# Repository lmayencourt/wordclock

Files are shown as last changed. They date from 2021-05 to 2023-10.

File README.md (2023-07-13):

# Wordclock
*WordClock* is a hobby project, aiming to create a nice looking time keeping art work.

The secondary goal is to have a project to experiment with various technologies like Rust, laser cutting, 3d printing, and various engineering skills like software architecture, software requirements, Test-Driven Development and technical documentation.

## User guide
The [User guide](https://lmayencourt.github.io/wordclock/user_guide_hw_v2.html) is part of the GitHub page documentation.

## Project management
A [GitHub project](https://github.com/users/lmayencourt/projects/1/) is used for tasks management.
The project follow the [Semantic versioning](https://semver.org) scheme.

## Deploy the firmware to an ESP32 board
````
. ~/export-esp.sh
cargo xbuild
espflash /dev/tty.usbserial-0001 crates/cross_compiled/target/xtensa-esp32-espidf/debug/cross_compiled --flash-freq 80M --flash-size 4MB --flash-mode DIO --speed 921600 --partition-table crates/cross_compiled/esp32_ota_partitions.csv
````

Add `--monitor` option to `espflash` to open the serial consol of the device directly after flashing.

Follow the instruction from https://github.com/esp-rs/esp-idf-template to create similar project from template.

## Documentation
`mdbook` is used for rendering the documentation in the `doc/` folder.

It can be generated with:
````
mdbook build
````

To build and open locally the documentation, use:
````
mdbook serve --open
````

A [GitHub page](https://lmayencourt.github.io/wordclock/) host the generated documentation, built automatically by GitHub action on every pull-request.

## Structure of the repository
````
.
|-- 3d printed              // 3d printed part of clock
|-- book.toml               // mdbook configuration for rendering the documentation
|-- Cargo.toml              // Rust workspace configuration
|-- crates                  // Rust source code
|-- doc                     // Project documentation
|-- LICENSE.txt
|-- ota-image               // Firmware Over The Air update image
|-- README.md               // This file
|-- target                  // Build output for Rust binary and documentation
````

## License
Licensed under MIT license ([LICENSE-MIT](LICENSE.txt) or http://opensource.org/licenses/MIT)

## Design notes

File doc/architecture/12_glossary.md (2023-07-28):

# Glossary

### ADR
Architecture Decision Record.

### FW
Firmware.

### NTP
Network Time Protocol.

### PCB
Printed Circuit Board.

### RTC
Real Time Clock.

### TDD
Test Driven Development.

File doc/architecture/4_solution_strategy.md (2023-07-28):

# Solution Strategy

| Quality goal | Achieved by | Rational |
| - | - | - |
| Reliability | Custom [PCB](12_glossary.md#PCB) design for the system hardware. | The electronic components are assembled on a professionally manufactured circuit board. No manual wiring is needed. |
| | [Rust programming language for the system software](8_crosscutting_concepts.md#rust-std-environment-for-esp32). | Use a system language that focus on correctness and provides native support for testing. |
| | [Documented software anomalies](8_crosscutting_concepts.md#document-software-anomalies). | Anomalies are documented and can be addressed later on by developers. |
| Autonomous | External [RTC](12_glossary.md#rtc) with a backup battery. | Local time is keep by a dedicated, high precision circuit. The backup battery allow the circuit to keep the time even when the system is not powered. |
| | Automatic time synchronization with [NTP](12_glossary.md#ntp). | No need for the user to enter the time manually, even after power lose. |
| Testability | [TDD for software module](8_crosscutting_concepts.md#test-driven-development-for-embedded-system).| Increase confidence of software working as expected. |
| | Follow [test-double](https://en.wikipedia.org/wiki/Test_double) names for testing. | Follow a standard, that helps developers to understand the tests structure and behavior. |

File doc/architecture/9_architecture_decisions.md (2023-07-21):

# Architecture decisions

All decisions are recorded according to the [Y-statement](https://socadk.github.io/design-practice-repository/artifact-templates/DPR-ArchitecturalDecisionRecordYForm.html) [ADR](12_glossary.md#ADR) template.

````
In the context of <use case/user story u>,
facing <concern c>
we decided for <option o1>
(and against <option o2,o3>)
(because <>)
to achieve <quality q>,
accepting <downside d>.
````

## PCB 1: LEDs matrix for display
In the context of designing a LEDs matrix for the *WordClock* display,
facing the need to choose LEDs component,
I decided to use WS2812 LEDs strip,
and neglected single LEDs or WS2812 LEDS,
to achieve low-cost and simple PCB assembly,
accepting the bigger dimension constraints of the LEDs strip.

## PCB 2: LEDs matrix routing
In the context of routing the LEDs matrix for the *WordClock* display,
facing the need to place the WS2812 LEDs strips on the [PCB](12_glossary.md#PCB),
I decided to keep the same layout as the *WordClock* hardware v1.0 (S like routing of the LEDs strips),
and neglected a "straight" layout,
to achieve a unified design across hardware iteration, limiting the number of variant,
accepting a slightly more complex LEDs matrix driver (half of the LEDs strips are inverted).

## FW 1: Configuration validity flag
In the context of implementing the persistent storage for the *WordClock* configuration,
facing the need to store a boolean value in persistent memory,
I decided to use a String value "0" and "1",
and neglected a dedicated boolean storage API,
to achieve a simple implementation, using the already implemented String storage API,
accepting a possible higher memory footprint of the boolean value in memory.

## FW 2: Directory layout for OTA images
In the context of releasing the OTA images for the new hardware v2 and Rust implementation,
facing the need to keep the hardware v1 and firmware v1.x.x/v2.x.x OTA working,
I decided to keep the hardware v1 OTA image at the root, and move the hardware v2 OTA image into a dedicated `ota-image/hardware-v2/` folder,
and neglected a dedicated branch `released-v2` or equivalent,
to achieve a backward compatible layout, and keep the single, easier to maintain release branch,
accepting that the hardware v1 OTA image stay for now in the root of the repository, and a migration process will be needed to move them to `ota-image/hardware-v2`.

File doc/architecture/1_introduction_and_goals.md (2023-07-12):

# Introduction and goals
*WordClock* is a hobby project, aiming to create a nice looking time keeping art work.

The secondary goal is to have a project to experiment with various technologies like Rust, laser cutting, 3d printing, and various engineering skills like software architecture, software requirements, Test-Driven Development and documentation.

This document is not limited to software architecture, but considers all the work realized by the *Embedded engineer*, include [PCB](12_glossary.md#PCB) design.

## Requirements overview
Essential features:
- Display current time, using your favorite Swiss-German dialect.
- Set system time, manually or automatically.
- Keep time accurately.
- Disable display during the night, if wanted.

## Quality goals
| ID | Quality | Motivation |
| - | - | - |
| QG1 | Reliability | The system shall function reliably under any circumstances. |
| QG2 | Autonomous | The system shall provide long up-time without human intervention. |
| QG3 | Testability | The architecture should allow easy testing of all main building blocks. |

## Stakeholder
| Stakeholder | Goal, Intentions |
| - | - |
| Owner | Want a nice time keeping device, that display the time in her favorite Swiss-German dialect. |
| Embedded engineer | Develop the electronic hardware and software that make the *WordClock* does its things; Learn and apply new software development skills. |
| Wood engineer | Manufacture the *WordClock* physical parts; Provides feedbacks and constraints on the *WordClock* hardware and software. |

## Use case
Developer:
1. Release new version of the firmware.
2. Install the firmware on the system.
3. Address *User* reported issue.

User:
1. Read time from system.
1. Configure the time of the system.
2. Configure the dialect of the system.
3. Configure Wi-Fi setup for automatic time setting.
4. Configure *Night time*, where the clock is not displaying the time.
5. Report issue to developer.
6. Update to latest released version of the firmware, without the need of advanced technical knowledge.

extra:
- Bluetooth configuration? not yet, but can be an upgrade.
- Chose color of the time? yes!

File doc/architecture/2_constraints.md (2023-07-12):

# Constraints

## Organizational constraints
| ID | Constraints | Motivation |
| - | - | - |
| OC1 | Affordable | The cost to assemble a *WordClock* should be low.|
| OC2 | Documentation | Use [arc42](https://arc42.org) as documentation template. |
| OC3 | Language | Use English for documentation. |

## Technical constraints
| ID | Constraints | Motivation |
| - | - | - |
| TC1 | Open-source | Privilege open-source solutions as software dependencies. |
| TC2 | Programming language  | Use [Rust](https://www.rust-lang.org) as programming language. |
| TC3 | Tools | Use as much as possible the Rust ecosystem for software development and documentation. |
| TC4 | Version control | Use [Git](https://git-scm.com) and GitHub for version control. |

## Electronic / Mechanical constraints
| ID | Constraints | Motivation |
| - | - | - |
| EMC1 | Dimensions | The electronic dimension should not exceed 190x190[mm] |
| EMC2 | Power cable | The electronic should be powered with a USB Micro-B cable. |
| EMC3 | User input | The electronic should provide at least a push-button for interacting with the system. |
| EMC4 | Labels  | The electronic should be labeled for user with no electronic knowledge. |
| EMC5 | Fixation | The electronic should provide 4x 4[mm] fixation holes. |

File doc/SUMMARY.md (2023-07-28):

# Summary

# System architecture
// Based on arc32 template document: https://docs.arc42.org/home/
- [Introduction and goals](./architecture/1_introduction_and_goals.md)
- [Constraints](./architecture/2_constraints.md)
- [Context and scope](./architecture/3_context_and_scope.md)
- [Solution strategy](./architecture/4_solution_strategy.md)
- [Building block view](./architecture/5_building_block_view.md)
- [Runtime view]()
- [Deployment view](./architecture/7_deployment_view.md)
- [Crosscutting concepts](./architecture/8_crosscutting_concepts.md)
- [Architecture decisions](./architecture/9_architecture_decisions.md)
- [Quality]()
- [Risks and technical debt]()
- [Glossary](./architecture/12_glossary.md)

---

# User guide

- [User guide 3D printed clock](./user_guide_hw_v1.md)
- [User guide wood clock](./user_guide_hw_v2.md)

---

# Developer

- [Developer setup](./developer_setup.md)
- [Bug avoided](./bug_avoided.md)
- [Esp32 learnings](./esp32_learnings.md)
- [Release process](./release_process.md)

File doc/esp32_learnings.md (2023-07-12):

# ESP32 developer learnings

## Reading the ESP32 partition table
Extract the partition table from a ESP32 device FLASH and dump the table to
stdout:
````
esptool.py read_flash 0x8000 0xc00 ptable.img
python3 crates/cross_compiled/.embuild/espressif/esp-idf/release-v4.4/components/partition_table/gen_esp32part.py ptable.img
````

Even better, using `espflash`:
````
espflash partition-table ptable.img
````

## Partition table must be flashed explicitly
When using the `espflash` command to program the device, the `--partition-table`
option should be used to update the device partition table.

````
espflash /dev/tty.usbserial-0001 crates/cross_compiled/target/xtensa-esp32-espidf/debug/cross_compiled --flash-freq 80M --flash-size 4MB --flash-mode DIO --speed 921600 --partition-table crates/cross_compiled/esp32_ota_partitions.csv
````
This is necessary to flash an image with FOTA capabilities.
Omitting to specify the partition-table in the command can allow to flash bigger images, like debug build.

## Partitions restrictions
Partitions must be 0x10000 (64kB) aligned.

## Generate an OTA image
Use the `espflash` tool to convert an `ELF` image to `bin` format:
````
espflash save-image ESP32 --flash-size 2MB crates/cross_compiled/target/xtensa-esp32-espidf/release/cross_compiled ota-test-img/ota_v0.1.0.bin
````

This also allow to see the real size of the image binary in FLASH.

## needed cargo-espflash?
````
cargo install cargo-espflash
````

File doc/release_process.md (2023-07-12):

# Release process

## Release tests
1. Run the unit-test: `cargo test`
2. Run the manual-test:
   1. Build the binary in release mode: `cargo xbuild --release`
   2. Flash the binary on the board: `espflash /dev/tty.usbserial-0001 crates/cross_compiled/target/xtensa-esp32-espidf/release/cross_compiled --flash-freq 80M --flash-size 4MB --fla
sh-mode DIO --speed 921600 --monitor --partition-table crates/cross_compiled/esp32_ota_partitions.csv`

### Manual tests
1. Invalid configuration -> start of configuration server `WordClock Configuration`.
2. HTML page is displayed properly.
3. Entering a valid configuration is parsed, and stored in persistent memory.
4. Valid configuration -> the system switch to display time state.
5. The time displayed is correct.
6. Manuel reset of the device with 'Reset' button loads configuration from persistent memory and start displaying time properly.
7. Pressing (long or short) the 'Enter' button switch the system to the menu.
8. Long press on FOTA menu triggers FOTA.
9. FOTA download succeed with log: `I (115661) application: Update ready, restart device`.
10. System restart in new version.

## Generate release binary
1. Build firmware in release mode: `cargo xbuild --release` 
2. Build the tagged OTA image: `cargo generate_ota release`
3. Commit and push changes to `main` branch.
4. Update the `released` branch to latest `master`.

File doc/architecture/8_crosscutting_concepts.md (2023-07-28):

# Crosscutting Concepts

## Document software anomalies
Software anomalies are documented in the code with the following template:
````
// Anomaly-xxx: <Short description>
//
// <Long description>
````

Where `Anomaly-xxx` represent a unique anomaly identifier, with `xxx` as a increasing 3 digits number.
The anomaly identifier should be used to refer to an anomaly in the documentation or in the code.

When an anomaly is resolved, the comment is removed from the code base. There is no centralized list of anomalies maintained. `git grep` should be used to recover past-anomalies descriptions.

## Rust std environment for ESP32

## Test driven development for embedded system
Every module should have unit-test that covers near 100% of the module functionalities. The tests should run on the developer machine to allow a fast development cycle.

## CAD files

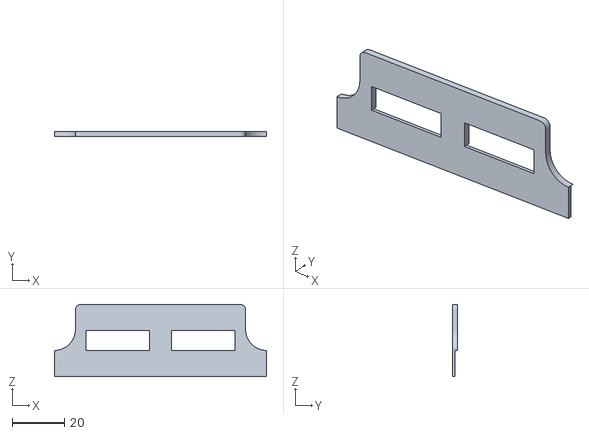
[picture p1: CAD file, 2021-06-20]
3d printed/leds_dot_frame.stl
81.2 x 2.00 x 27.6

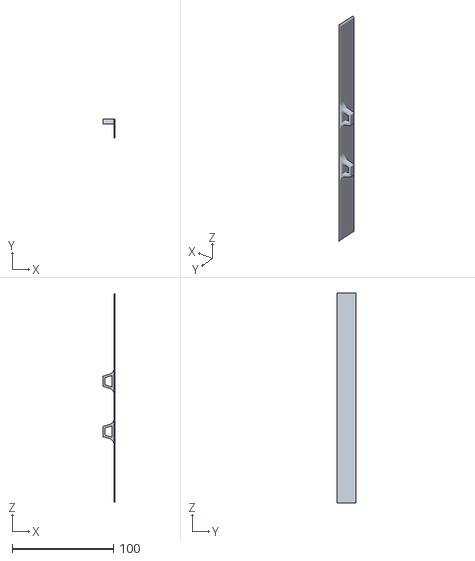
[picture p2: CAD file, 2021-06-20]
3d printed/printed_side_supported.stl
12.3 x 19.0 x 207.9

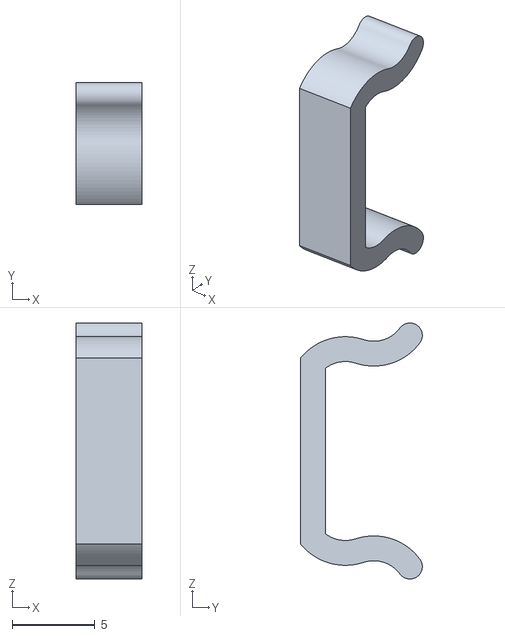
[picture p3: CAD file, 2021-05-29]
3d printed/matrix_clip.stl
4.00 x 7.35 x 15.5

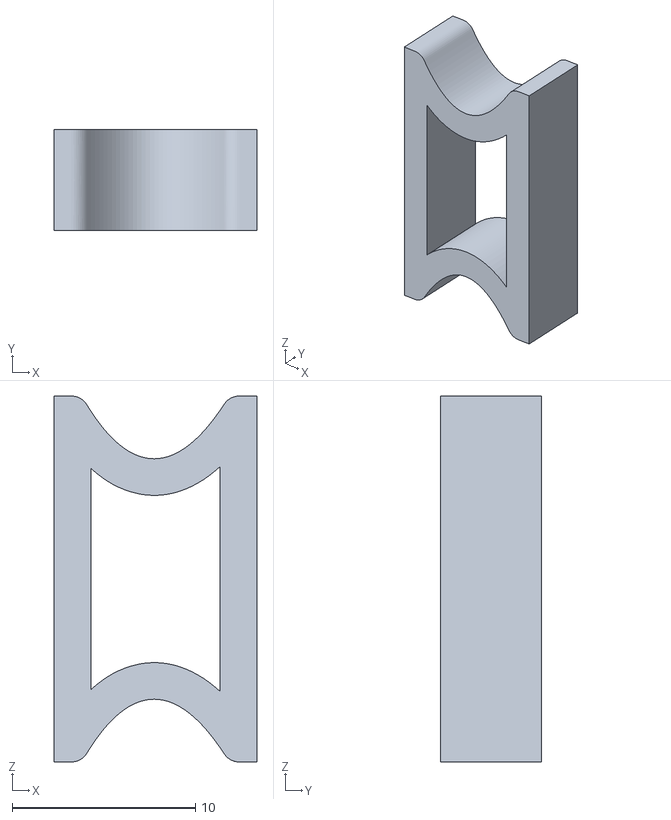
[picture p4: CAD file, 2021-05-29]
3d printed/side_support.stl
11.1 x 5.50 x 20.0

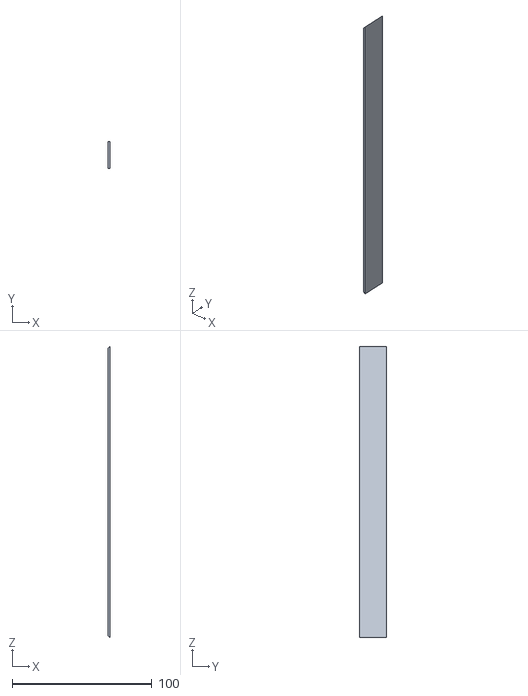
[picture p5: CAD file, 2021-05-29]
3d printed/printed_side.stl
1.20 x 19.0 x 207.9

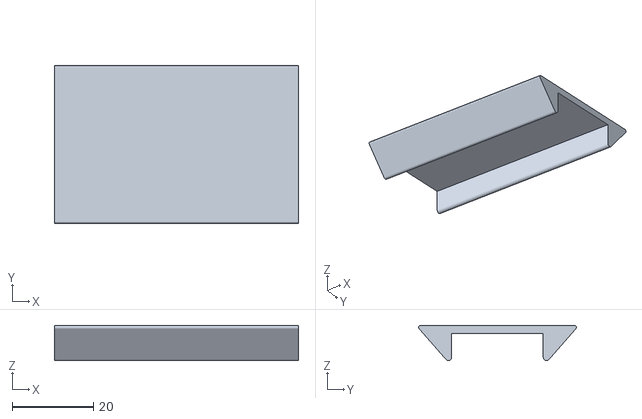
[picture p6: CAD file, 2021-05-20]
3d printed/socle.stl
60.0 x 38.8 x 8.67

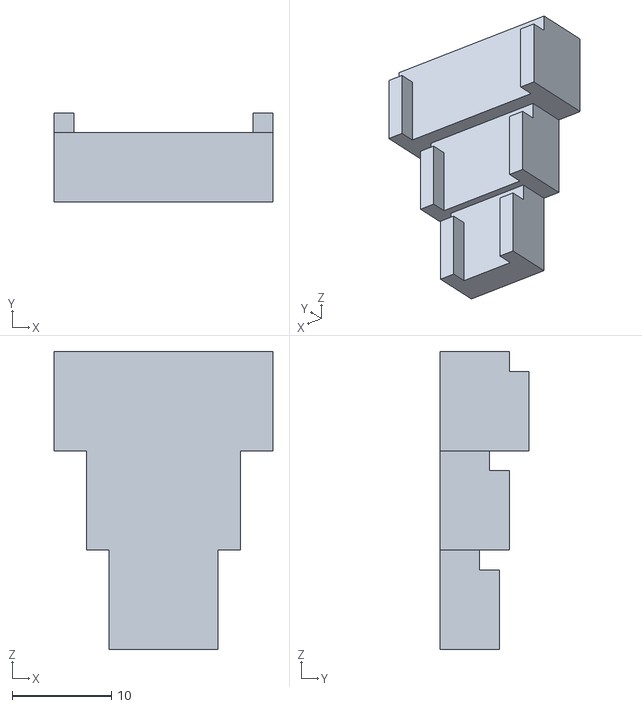
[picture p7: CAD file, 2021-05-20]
3d printed/matrix_solder_helper.stl
22.0 x 9.00 x 30.0

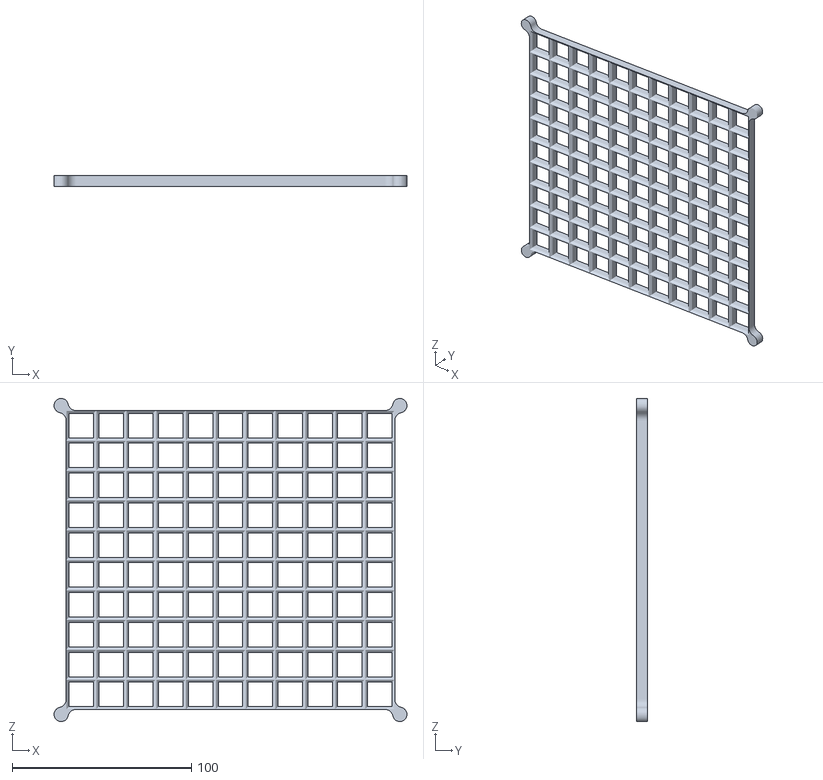
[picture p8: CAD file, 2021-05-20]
3d printed/grid.stl
196.9 x 6.00 x 180.3

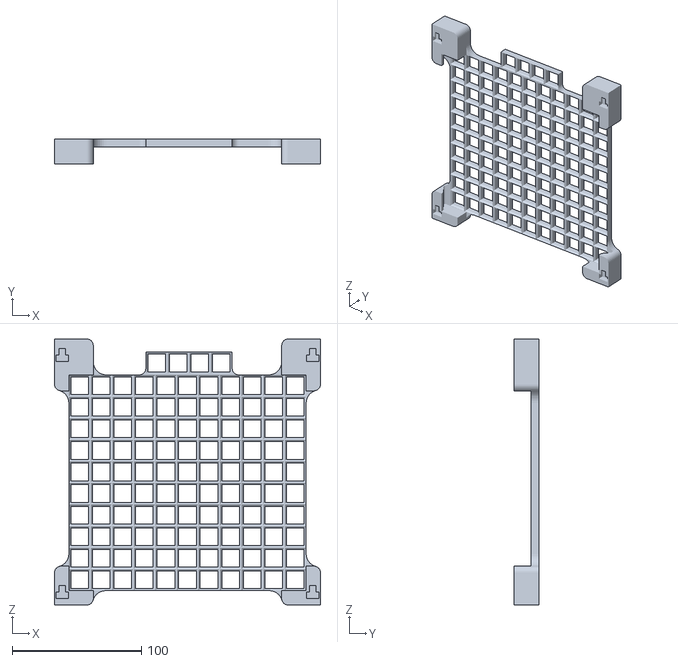
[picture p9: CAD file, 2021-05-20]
3d printed/grid_v2.stl
205.5 x 19.0 x 205.5

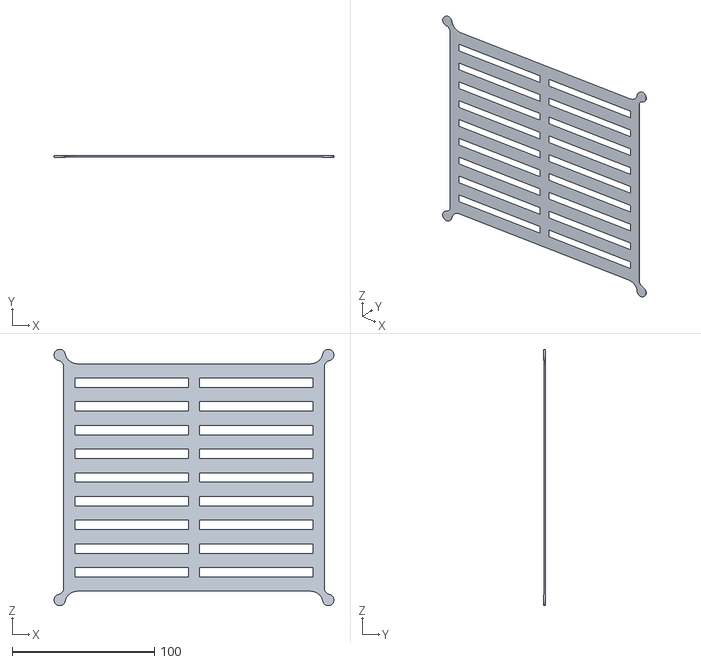
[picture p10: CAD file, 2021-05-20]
3d printed/leds_frame.stl
197.0 x 1.50 x 180.3

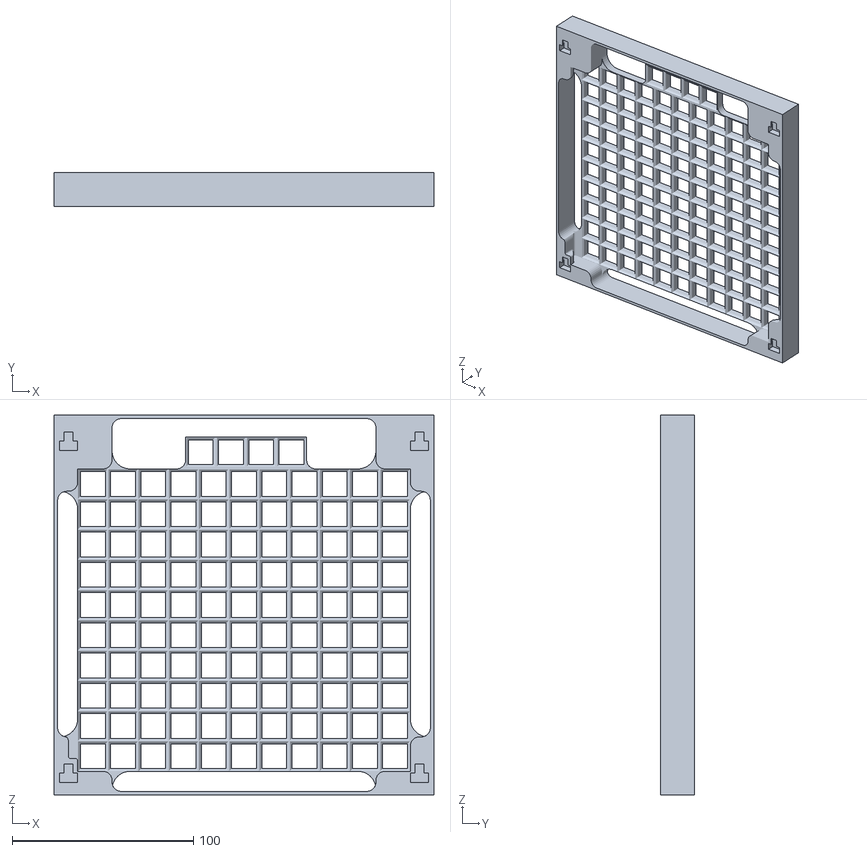
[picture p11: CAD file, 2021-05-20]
3d printed/grid_v2_framed.stl
209.5 x 19.0 x 209.5

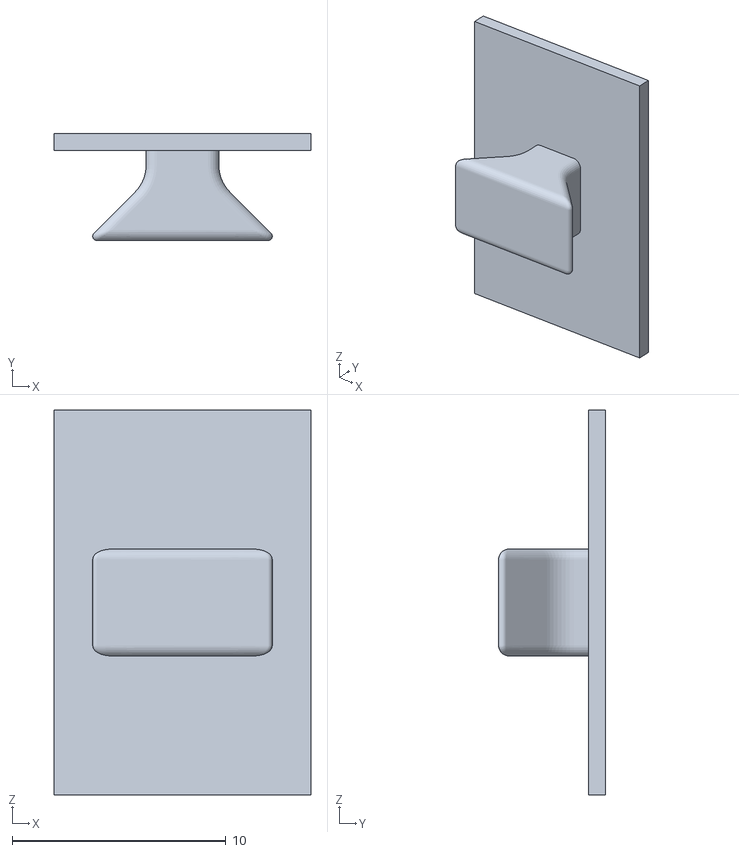
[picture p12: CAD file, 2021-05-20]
3d printed/stencil_holder_dummy.stl
12.0 x 5.00 x 18.0

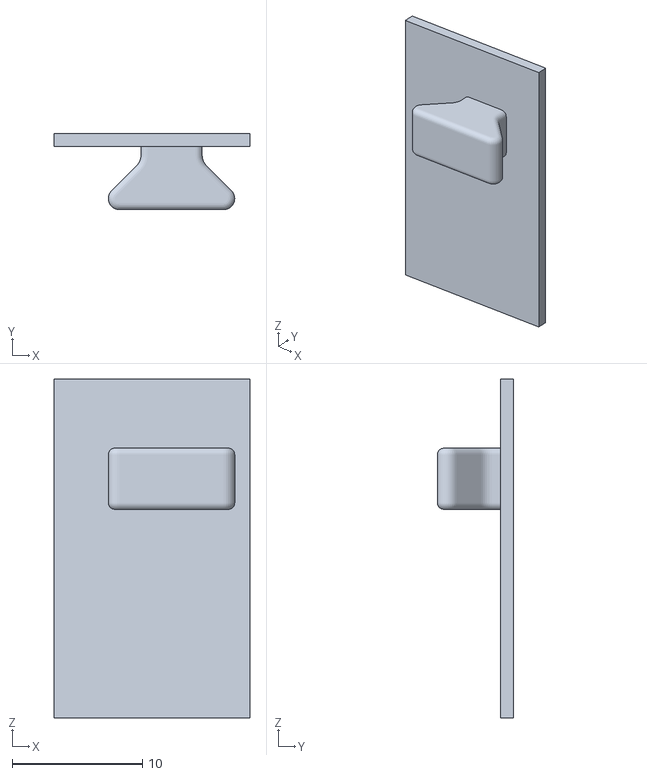
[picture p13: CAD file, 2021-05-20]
3d printed/stencil_holder.stl
15.0 x 5.85 x 26.0

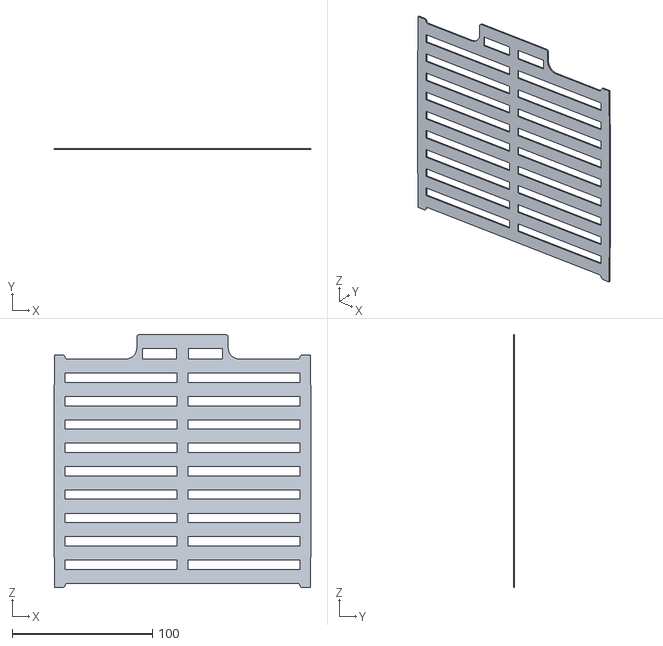
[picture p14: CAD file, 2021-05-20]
3d printed/leds_frame_v2.stl
183.3 x 1.00 x 180.6

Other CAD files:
3d printed/stencil_holder_v2.stl

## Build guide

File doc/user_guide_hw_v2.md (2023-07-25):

# User guide wood clock
This covers the second iteration of the *WordClock*, with custom hardware and firmware v3.x.x

## Display meanings
When you power the device, it will display:
 * 1 dot: Startup.
 * 2 dots: Configuration mode.
 * 1 red cross: Error. Press "Restart" button to restart the clock.
If the startup sequence went successfully, the device will start displaying the time.

### Configuration mode
The device create a WiFi access point called "WordClock Configuration". In order to configure the clock, you must connect to it and access the page [http://192.168.71.1](http://192.168.71.1) in a browser. Enter your wifi name (SSID) and your wifi password.
If you want the clock to be off during the night, set the "Night mode" start and end times.

## Menu
To enter the menu, press the "Enter" button until the first dots is displayed, when the device is displaying the time. A single push of the "Enter" button changes the menu, a long push (< 2 secs) validate the menu selection and trigger the associated actions:
 * 1 dot: Check if a new version of the firmware is available and download it.
 * 2 dots: Erase the current configuration and switch back to configuration mode.
 * 3 dots: Go back to time display.

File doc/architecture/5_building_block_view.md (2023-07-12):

# Building Block View

This chapter explains the building blocks of the *WordClock* system, and its decomposition in sub-system.

## White box of the *WordClock*
level_1

| Name | Responsibility |
| - | - |
| Application | provides the high-level system behavior. |
| Platform abstraction | decouples the Application implementation from the platform specific hardware. | 
| Platform | contains all the hardware specific features. |
| Real Time Clock | is the hardware component responsible to keep track of the time when the system is powered off. |
| Led Matrix | is the hardware component used as display. |

level_2

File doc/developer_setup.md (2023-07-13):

# Developer setup

## VS Code configuration for Rust

Create a `.vscode/settings.json` with the following content:
````
{
    "rust-analyzer.linkedProjects": [
        "Cargo.toml",
        "crates/cross_compiled/Cargo.toml",
    ]
}
````

## Setup rust analyzer for ESP32
setup the environment variables in `.cargo/config.toml` to match the `export-esp.sh` values.

## Rust references

- [Rust by Example](https://doc.rust-lang.org/rust-by-example/index.html)
- [rustdoc book](https://doc.rust-lang.org/rustdoc/what-is-rustdoc.html)
- [Rust API Guidelines](https://rust-lang.github.io/api-guidelines/about.html)
- [Large Rust Workspaces](https://matklad.github.io/2021/08/22/large-rust-workspaces.html)

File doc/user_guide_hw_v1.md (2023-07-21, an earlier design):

# User guide 3D printed clock
This covers the first iteration of the *WordClock*, with hardware v1, firmware v1.x.x and v2.x.x.

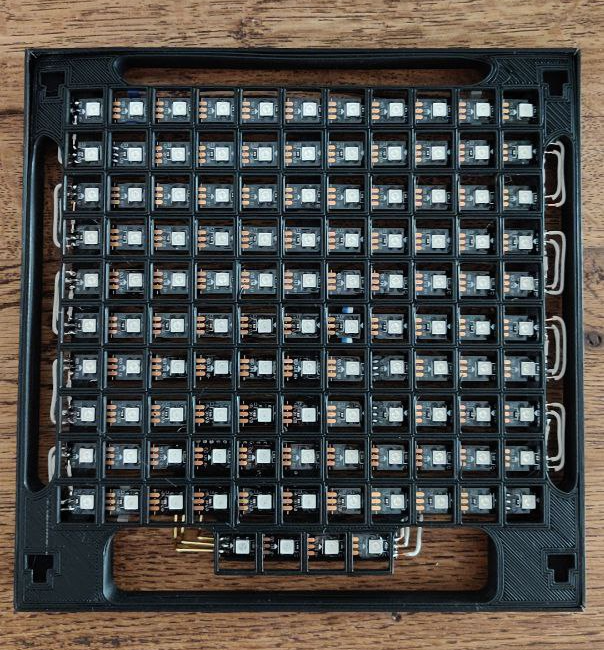
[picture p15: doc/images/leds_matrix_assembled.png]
hardware_v1


### Configuration
Connect to "WordClock" wifi and go to [http://192.168.4.1](http://192.168.4.1) in a browser. Enter your wifi name (SSID) and your wifi password.
If you want the clock to be off during the night, set the "Night mode" start and end times.

> **Note:** You may need to restart the clock by pressing the "EN" button.

### Menu
To enter the menu, press the "BOOT" button until the "uhr" is displayed (it may take up to 15 secs to reach the menu). A single push of the "BOOT" button changes the menu, a long push (< 2 secs) validate the menu selection and trigger the associated actions:
 * uhr: Go back to time display.
 * eis: Check if a new version of the firmware is available and download it.
 * zwöi: Erase the current configuration and switch back to configuration mode.

### Display meanings
 * 1 green dot: Booting.
 * 2 blue dots: Configuration mode.
 * 1 blinking red dot: Error. Press "EN" bouton to restart the clock.

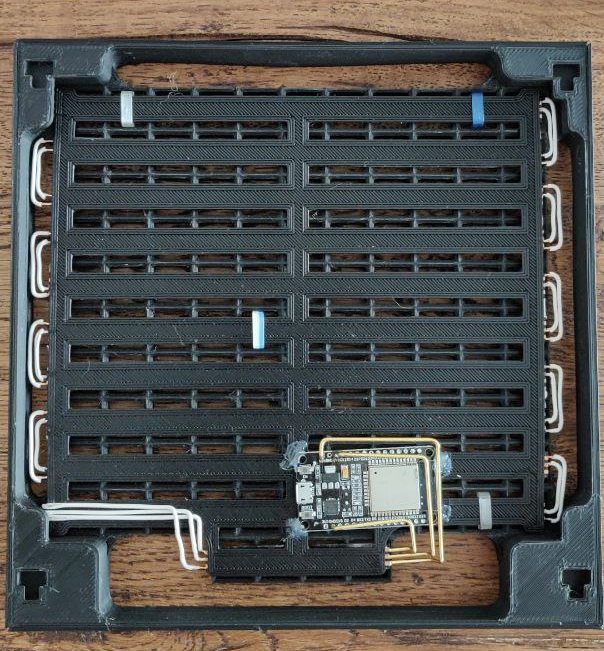
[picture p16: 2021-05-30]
doc/images/backside_assembled.png

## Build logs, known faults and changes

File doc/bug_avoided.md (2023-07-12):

# Bug that Rust catch when compiling

## Compute `hour_to_display` and forget to use it! 
````
fn draw_time(&mut self, time: Time) -> Result<()> {
        let mut hour_to_display = time.hour;
        if time.minute >=25 {
            hour_to_display = time.hour+1;
        }
        // 24 -> 12
		if hour_to_display > 12 {
			hour_to_display = hour_to_display - 12 ;
		}
		// midnight
		if hour_to_display == 0 {
			hour_to_display = 12;
		}
        self.set_pixel_from_lut(&BARN_HOURS_LOOKUP_TABLE, (time.hour-1) as usize, RED);
}
````

`````
warning: value assigned to `hour_to_display` is never read
   --> src/display.rs:154:4
    |
154 |             hour_to_display = 12;
    |             ^^^^^^^^^^^^^^^
    |
    = help: maybe it is overwritten before being read?
    = note: `#[warn(unused_assignments)]` on by default
````

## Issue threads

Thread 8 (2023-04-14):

Implement display driver

lmayencourt, 2023-04-14:
Based on the LEDs driver, implement a high-level display controller.
The display controller should provide an interface to control the high-level "gui" element:
- display the time
- display an error
- display a message
- display a progress bar
- ...

Closed 2023-04-21.

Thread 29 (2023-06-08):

Implement menu

lmayencourt, 2023-06-08:

lmayencourt, 2023-06-08:
When the control board "Enter" button is pushed, the device should enter the menu.

A short push should switch to next menu,
A long push should select the menu item

Closed 2023-06-08.

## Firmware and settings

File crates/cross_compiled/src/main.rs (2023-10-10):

/* SPDX-License-Identifier: MIT
 * Copyright (c) 2023 Louis Mayencourt
 */

use std::thread;
use std::time::Duration;

use cross_compiled::esp32_soc::Esp32SocCpuTime;
use log::*;
use anyhow::{Result};

// use embedded_svc::{
//     http::{
//         client::{Client, Request, RequestWrite, Response},
//         Status,
//     },
//     io::Read,
// };
// use esp_idf_svc::http::client::{EspHttpClient, EspHttpClientConfiguration};

use esp_idf_sys as _; // If using the `binstart` feature of `esp-idf-sys`, always keep this module imported

use esp_idf_hal::prelude::*;
use esp_idf_hal::gpio::*;
use esp_idf_hal::i2c::I2cDriver;
use esp_idf_hal::i2c::I2cConfig;

use esp_idf_svc::systime::EspSystemTime;

use application::Application;
use application::behaviour::*;
use application::build_version::BUILD_VERSION_STRING;
use application::network::Network;
use application::time_source_manager::TimeSourceManager;
use application::version::Version;

use cross_compiled::esp32_soc::Esp32Soc;
use cross_compiled::esp32_soc::Esp32SocSystemTime;
use cross_compiled::ds3231_board_rtc::Ds3231Rtc;
use cross_compiled::led_driver::WS2812;
use cross_compiled::http_server;
use cross_compiled::network;
use cross_compiled::network_time;
use cross_compiled::ota_update::OtaUpdate;
use cross_compiled::persistent_settings::NonVolatileStorage;
use cross_compiled::rgb_led_strip_matrix;

const ACCESS_POINT_NAME: &str = "WordClock Configuration";

fn main() -> Result<()> {
    // It is necessary to call this function once. Otherwise some patches to the runtime
    // implemented by esp-idf-sys might not link properly. See https://github.com/esp-rs/esp-idf-template/issues/71
    esp_idf_sys::link_patches();

    esp_idf_svc::log::EspLogger::initialize_default();
    info!("WordClock firmware ({}) - ESP32!", Version::from_string(BUILD_VERSION_STRING)?);

    let peripherals = Peripherals::take().unwrap();
    let led = PinDriver::output(peripherals.pins.gpio2)?;
    let mut heart_beat = HearthBeat::new(led);

    let push_button = PinDriver::input(peripherals.pins.gpio0)?;

    let led_driver = WS2812::new(114, peripherals.pins.gpio15, peripherals.rmt.channel0)?;
    let display = rgb_led_strip_matrix::RgbLedStripMatrix::new(led_driver)?;

    let i2c_config = I2cConfig::new().baudrate(100.kHz().into());
    let i2c_master = I2cDriver::new(peripherals.i2c0, peripherals.pins.gpio21, peripherals.pins.gpio22, &i2c_config)?;
    let board_time = Box::new(Ds3231Rtc::new(i2c_master));

    let mut network = network::WifiNetwork::new(peripherals.modem)?;

    // Anomaly-001: WiFi driver need NVS to be initialized
    //
    // Needed for now to avoid wifi error:
    // E (2691) phy_init: esp_phy_load_cal_data_from_nvs: NVS has not been initialized. Call nvs_flash_init before starting WiFi/BT.
    network.configure("dummy","1234")?;
    network.fake_connect()?;

    // Anomaly-002: WiFi can't be configured in soft AP after access to NVS
    //
    // Setting up the access point after reading the persistent settings in NVS
    // partition fails due to an invalid NVS handle in the WiFi driver.
    // Start the WiFi soft AP here to provide an already configured network to the application.
    // The application code can switch to Station mode afterward without issue.
    network.setup_access_point(ACCESS_POINT_NAME)?;
    let http = http_server::HttpServer::new()?;

    let system_time = Esp32SocSystemTime::new();
    let cpu_time = Box::new(Esp32SocCpuTime::new());
    let network_time = Box::new(network_time::NetworkTime::new());
    let time_source = TimeSourceManager::new(system_time, cpu_time, Some(board_time), Some(network_time));

    let persistent_storage = NonVolatileStorage;
    let power_manager = Esp32Soc;
    let firmware_update = OtaUpdate;
    let mut application = Application::new(display, time_source, persistent_storage, network, http, power_manager, firmware_update);

    application.publish_event(Event::Init);
    application.run();

    // Display check
    // for n in 0..1 {
    //     display.draw_all()?;
    //     thread::sleep(Duration::from_millis(1000));
    //     display.clear()?;
    //     thread::sleep(Duration::from_millis(2000));
    // }

    let mut tick_counter:u32 = 0;
    let mut push_duration:u32;

    loop {
        application.run();
        heart_beat.run();

        // Blocking "Enter" push-button detection
        if push_button.is_low() {
            push_duration = 0;

            while push_button.is_low() {
                thread::sleep(Duration::from_millis(100));
                push_duration += 100;
            }

            if push_duration < 2000 {
                application.publish_event(Event::EnterShortPush);
            } else {
                application.publish_event(Event::EnterLongPush);
            }
        }

        if application.get_current_state() == State::DisplayTime {
            if tick_counter >=10 {
                tick_counter = 0;
                application.publish_event(Event::Tick);
                info!("Network time epoch: {:?}", network_time::get_epoch_time());
                info!("Parsed network time: {}", network_time::get_time());
                info!("System time: {:?}", EspSystemTime {}.now());
            } else {
                tick_counter += 1;
            }
        }

        // Main loop iterate every 100ms
        thread::sleep(Duration::from_millis(100));
    }
}

/// Generate a regular visual signal of the system health
///
/// Blink the board LED every second, for 100ms. This implementation assumes to
/// be called every 100ms.
struct HearthBeat<'a> {
    led: PinDriver<'a, Gpio2, Output>,
    tick_counter:u32,
}

impl<'a> HearthBeat<'a> {
    pub fn new(led:PinDriver<'a, Gpio2, Output>) -> Self {
        Self { led, tick_counter:0 }
    }

    /// Must be called every 100ms
    pub fn run(&mut self) {
        match self.tick_counter {
            0 => self.led.set_low().unwrap(),
            9 => self.led.set_high().unwrap(),
            _ => (),
        }

        if self.tick_counter >= 10 {
            self.tick_counter = 0;
        } else {
            self.tick_counter += 1;
        }
    }
}

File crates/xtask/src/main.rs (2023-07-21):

use std::{env, io::Write};
use std::fs::File;

use anyhow::anyhow;
use xshell::{cmd, Shell};

fn main() -> Result<(), anyhow::Error> {
    let args = env::args().skip(1).collect::<Vec<_>>();
    let args = args.iter().map(|s| &**s).collect::<Vec<_>>();

    if args.len() == 0 {
        usage();
        return Err(anyhow!("No argument provided"));
    }

    match args[0] {
        "build" => build_target(&args[1..]),
        "check" => check_target(&args[1..]),
        "clean" => clean_target(),
        "flash" => flash_target(&args[1..]),
        "doc" => doc_target(),
        "uml" => generate_uml_images(),
        "generate_ota" => generate_ota_image(&args[1..]),
        _ => {
            usage();
            Ok(())
        }
    }
}

fn usage() {
    println!("USAGE cargo xtask [build|check|clean|flash|doc|uml|generate_ota]");
}

fn build_target(args: &[&str]) -> Result<(), anyhow::Error> {
    let sh = Shell::new()?;

    // Generate build version file from git describe
    // Remove the first char, as the git describe return prefix the version with 'v', e.g.: v1.2.3
    let git_version = cmd!(sh, "git describe").read()?;
    let git_version = &git_version[1..&git_version.len()-1];
    let mut version_file = File::create("crates/application/src/build_version.rs")?;
    writeln!(version_file, "// This file is generated automatically during build with the result of the git describe command.")?;
    writeln!(version_file, "// Do not edit manually.\n")?;
    write!(version_file, "pub const BUILD_VERSION_STRING: &str = \"{}\";", git_version)?;

    sh.change_dir("crates/cross_compiled");
    cmd!(sh, "rustup run esp cargo build {args...}").run()?;
    Ok(())
}

fn check_target(args: &[&str]) -> Result<(), anyhow::Error> {
    let sh = Shell::new()?;
    sh.change_dir("crates/cross_compiled");
    cmd!(sh, "rustup run esp cargo check {args...}").run()?;
    Ok(())
}

fn clean_target() -> Result<(), anyhow::Error> {
    let sh = Shell::new()?;
    sh.change_dir("crates/cross_compiled");
    cmd!(sh, "rustup run esp cargo clean").run()?;
    Ok(())
}

fn flash_target(args: &[&str]) -> Result<(), anyhow::Error> {
    let sh = Shell::new()?;
    sh.change_dir("crates/cross_compiled");
    cmd!(sh, "espflash /dev/tty.usbserial-0001 target/xtensa-esp32-espidf/debug/cross_compiled --flash-freq 80M --flash-size 4MB --flash-mode DIO --speed 921600 --partition-table esp32_ota_partitions.csv {args...}").run()?;

    Ok(())
}

fn doc_target() -> Result<(), anyhow::Error> {
    let sh = Shell::new()?;
    sh.change_dir("crates/cross_compiled");
    cmd!(sh, "rustup run esp cargo doc --open").run()?;
    Ok(())
}

fn generate_uml_images() -> Result<(), anyhow::Error> {
    let sh = Shell::new()?;
    sh.change_dir("doc/uml");

    let mut output_dir = sh.current_dir();
    output_dir.push("exported");
    cmd!(sh, "rm -rf exported").run()?;
    cmd!(sh, "plantuml -png **.puml -o {output_dir}").run()?;

    Ok(())
}

fn generate_ota_image(args: &[&str]) -> Result<(), anyhow::Error> {
    let sh = Shell::new()?;
    let git_version = cmd!(sh, "git describe").read()?;
    println!("Releasing firmware: {:?}", git_version);

    let build_type: &str;
    match &args[..] {
        ["release"] => build_type = "release",
        ["debug"] => build_type = "debug",
        _ => {
            return Err(anyhow!(
                "Unsupported argument {:?}, must be [release|debug]",
                args
            ))
        }
    }
    cmd!(sh, "espflash save-image ESP32 --flash-size 2MB crates/cross_compiled/target/xtensa-esp32-espidf/{build_type}/cross_compiled ota-image/hardware-v2/firmware-ota.bin").run()?;
    let mut version_file = File::create("ota-image/hardware-v2/version.txt")?;
    version_file.write_all(git_version.as_bytes())?;

    Ok(())
}

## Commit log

2021-05-20 Initial commit
    Implemented yet:
    - LEDs matrice driver
    - NTP time
    - Configuration with Wifi
    To do for first release:
    - Summer time
2021-05-20 Add 3d models
    [calibration.stl, frame_corner.stl, frame_corner_M.stl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]
2021-05-29 Update 3d models
    [matrix_clip.stl, printed_side.stl, side_support.stl]
2021-05-29 Fix flitching after deep-sleep wakeup
    Use RTC memory to store the current displayed time.
    Don't update the display if time hasn't changed.
2022-02-25 Build arduino core library
2022-11-27 Use python3 in xtensa esp32 tools
2023-02-26 Add LED blink
2023-03-19 Improve error handling with anyhow crate
    [main.rs]
2023-03-24 Use logging crate instead of println
2023-04-09 Add led driver for WS2812
2023-04-17 Remove Arduino C/C++ firmware related files
2023-04-20 Remove unnecessary files
    [calibration.stl, stencil.stl, stencil_bern-1_5.stl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]
2023-04-20 Complete WS2812 led driver
2023-04-21 Rework directory layout into a cargo workspace
    Define a cargo workspace with a flat structure in `crates/` for the
    sources files.
    This allow to separate portable and target-specific code. Portable
    code can then be tested directly on the host development machine.
    [main.rs]
2023-04-21 Use xtask to build from root directory
    build firmware for ESP32 with:
    `cargo xtask build`
2023-04-30 Add firmware over the air (FOTA) update
    [esp32_ota_partitions.csv]
2023-04-30 Use GPIO pin for wordclock hardware v2
2023-05-05 Add system state machine
    Implement the device behaviour that follow system desired state-chart.
2023-05-10 Add device configuration module
    Storage agnostic persistent configuration for the device settings.
2023-05-18 Fix argument handling in xtask
    [main.rs]
2023-06-06 Temporary fix for WiFi connection
    For unkown reason, the WiFi module init doesn't work properly when done
    during the startup state. No error returned, but WiFi never connect afterward.
    Use a dummy connection in the main to address fix for now.
    [main.rs]
2023-06-08 Implement menu
    Use for now a blocking implementation for the button press detection.
    This is not an optimal implementation, but the simplest one. Best would
    be to move this code into a button "active" module, that generate long/short
    push event. A shared, mutable event queue must be implemented for this first.
    [main.rs]
2023-07-05 Start configuration mode when valid configuration is in persistent memory
    Due to an unknown issue with NVS and WiFi, the WiFi can't be setup as soft Access Point
    after reading the configuraiton in NVS.
    As a workaround, configure the WiFi as AP in main and start the application afterward.
    [main.rs]
2023-07-11 Add Power manager module
    Provide an abstracted interface to manage the board power mode.
    Currently only provide a reset function.
    [main.rs]
2023-07-21 Add build-time version
    Every firmware have now an hard-coded version, generated with the
    git describe command and written in a Rust source file.
    This allow to know which version is currently installed on the device
    by looking at the log. This is specially useful for FOTA testing.
2023-07-21 Move hardware v2 OTA binary into a dedicated repository
    The compatibility with first generation of firmware and hardware must
    be kept on the released branch.
    To not break old FOTA of hardware-v1, the OTA image stay currently in
    the root of the repo. An update for hardware-v1 may solve this issue later.
    [main.rs]
2023-08-16 Add minimal DS3231 RTC driver
2023-10-09 Add time source manager
    Handle 2 externals time sources: board RTC and network time.
    All the use-case to have no network or no board RTC.
    No network is for situation where no WiFi is available.
    No board RTC is for backward compatibility with first hardware version.
